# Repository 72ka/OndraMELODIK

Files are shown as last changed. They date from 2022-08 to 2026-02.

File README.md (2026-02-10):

# OndraMELODIK

 Music interface for the famous czechoslovak home computer [TESLA Ondra SPO186](http://www.ondraspo186.8u.cz/ "Tento web se zabývá československým počítačem Tesla Ondra SPO 186")

 SMD version with Joystick interface, but without printer connector by Solaris104 here: [Ondra JOY/MELODIK](http://www.ondraspo186.8u.cz/?p=641).
 
 You can read the OndraMELODIK story in [this article](http://www.ondraspo186.8u.cz/?p=588) (Czech language)

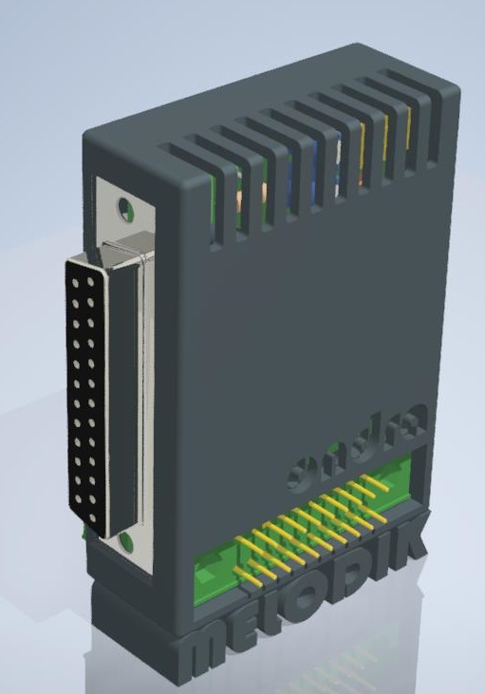
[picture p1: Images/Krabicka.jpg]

> OndraMELODIK music interface - introduced in 2022


> Czechoslovak home computer Tesla Ondra SPO186 - introduced in 1985

### Features

- Opensource hardware
- Based on [SN76489](https://en.wikipedia.org/wiki/Texas_Instruments_SN76489) chip
- Compatible with [OndraSD](https://sites.google.com/site/ondraspo186/4-rom-card-sd) interface, OndraMELODIK is through out interface
- It can play 3 channels square wave, 1 channel noise simultaneously
- Minimum CPU usage - two byte transfer, in some cases even one byte transfer, this is essential for such a slow computer
- External interface - no changes on the computer
- Designed with 80´ technology - all parts was available in 1985
- DB25 Centronics printer port (formerly known as LPT from PC) in one case
- 3D printed case STL files included

### Usage

1. Turn off your belowed Ondra
2. Plug OndraMELODIK to Ondra X1 connector
3. Optionally plug the OndraSD or whatever interface to the OndraMELODIK

#### As music interface

4. Switch the switch to the MELODIK position
5. Plug the 3.5mm audio jack of your favorite audio system
6. Turn on Ondra
7. If you hear some noise or tone, just push once the RESET button
8. Load the software [meltest.bin](https://github.com/72ka/OndraMELODIK/raw/main/Software/demo_test.bin) from this repository and test the device and listen the music

> Notice: If you perform just Ondra reset and some tone or noise is coming out, just push the RESET button once

#### As printer interface

4. Switch the switch to the PRINTER position
5. Be sure you dont have plugged in the audio jack or the audio system is turned off
6. Plug your printer using standard PC printer cable
7. Turn on Ondra
8. Print using Ondra's monitor, BASIC or TEDIT (if you forget to unplug the audio jack and strange noises are coming out, it is normal)

### Preview

How it sounds

https://www.youtube.com/watch?v=u5RyUs0VGdg

How it prints

https://www.youtube.com/watch?v=VYsxnQOKPeM

### Real photos

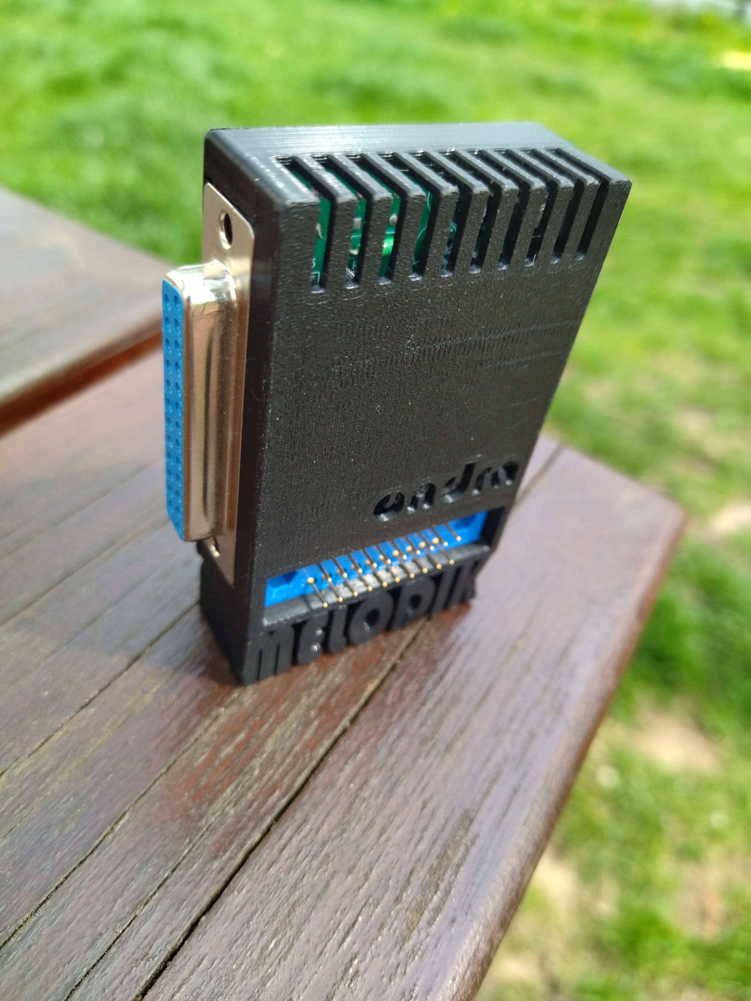
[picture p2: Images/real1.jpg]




### License

MIT license

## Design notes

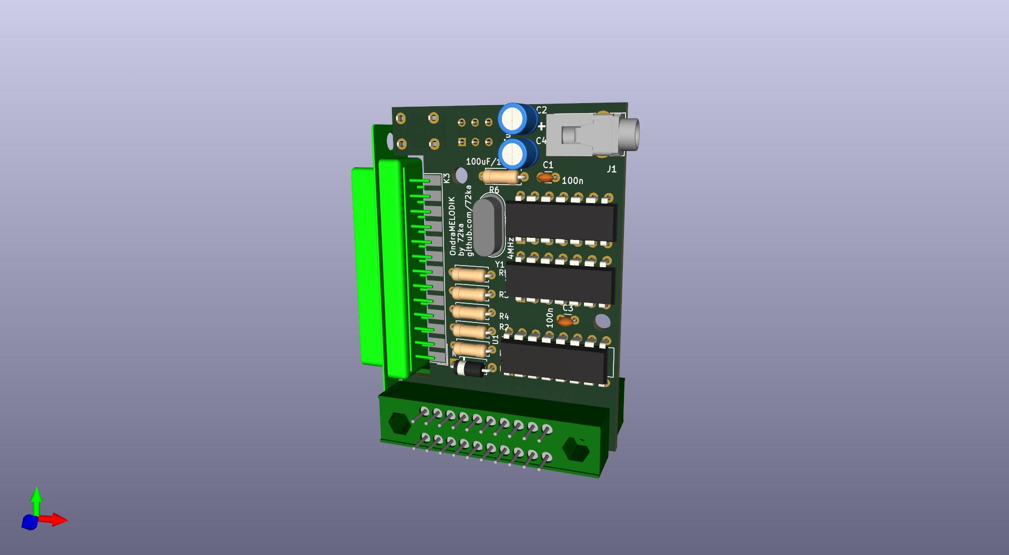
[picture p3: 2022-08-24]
Images/OndraMelodikTisk_zadek.jpg

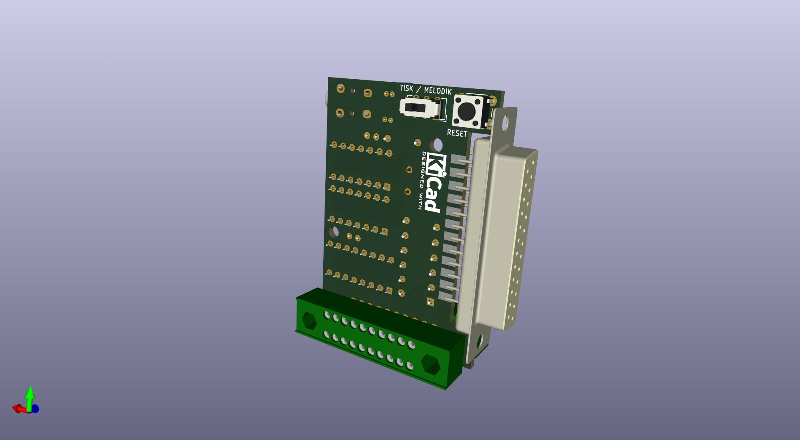
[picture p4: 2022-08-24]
Images/OndraMelodikTisk_predek.jpg

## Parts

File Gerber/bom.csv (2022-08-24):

Designator | Footprint | Quantity | Value | LCSC Part #
U3 | DIP-14_W7.62mm | 1 | 74LS74
R6 | R_Axial_DIN0207_L6.3mm_D2.5mm_P7.62mm_Horizontal | 1 | 2k
R2 | R_Axial_DIN0207_L6.3mm_D2.5mm_P7.62mm_Horizontal | 1 | 470R
R4 | R_Axial_DIN0207_L6.3mm_D2.5mm_P7.62mm_Horizontal | 1 | 10k
U1 | DIP-16_W7.62mm | 1 | SN76489
C4 | C_Radial_D6.3mm_H7.0mm_P2.50mm | 1 | 100uF/6,3V
R5 | R_Axial_DIN0207_L6.3mm_D2.5mm_P7.62mm_Horizontal | 1 | 10k
K2 | TX5112011 | 1 | ONDRA_X1
C1 | C_Disc_D3.0mm_W1.6mm_P2.50mm | 1 | 100n
K3 | DSUB-25_Female_EdgeMount_P2.77mm | 1 | Printer (optional)
U2 | DIP-14_W7.62mm | 1 | 74LS00
R1 | R_Axial_DIN0207_L6.3mm_D2.5mm_P7.62mm_Horizontal | 1 | 470R
D1 | D_A-405_P7.62mm_Horizontal | 1 | KA206
R3 | R_Axial_DIN0207_L6.3mm_D2.5mm_P7.62mm_Horizontal | 1 | 12k
C2 | C_Radial_D5.0mm_H7.0mm_P2.00mm | 1 | 4,7uF/50V
C3 | C_Disc_D3.0mm_W1.6mm_P2.50mm | 1 | 100n
J1 | Jack_3.5mm_Lumberg_1503_07_Horizontal | 1 | AudioJack
K1 | TX5112011 | 1 | ONDRA_X1
Y1 | Crystal_HC49-4H_Vertical | 1 | 4MHz
SW1 | SW_PUSH_6mm | 1 | RESET
SW2 | SW_CuK_JS202011CQN_DPDT_Straight | 1 | MELODIK / TISK

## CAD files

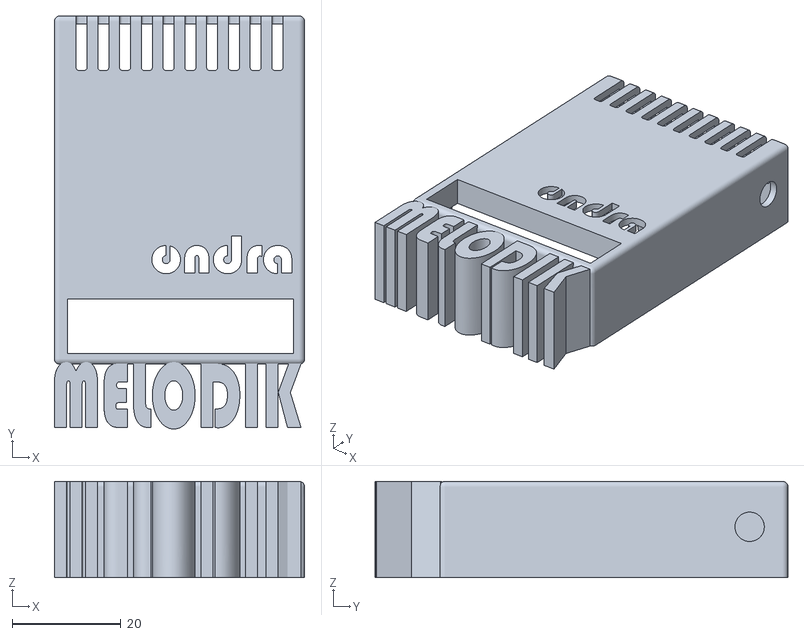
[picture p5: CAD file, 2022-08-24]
Case/Krabicka1.stl
46.0 x 75.9 x 17.7

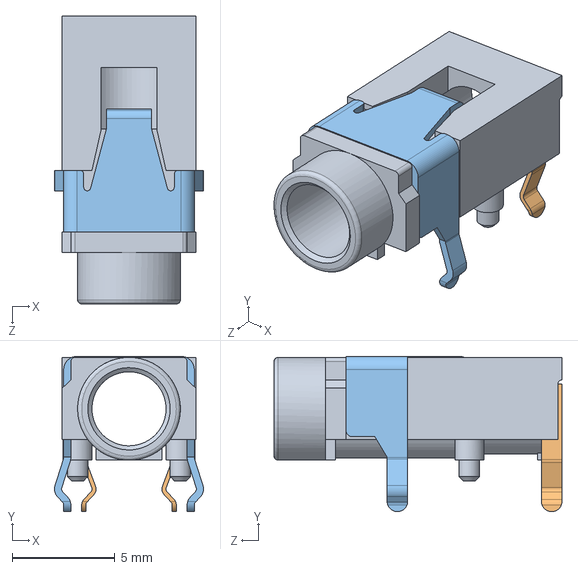
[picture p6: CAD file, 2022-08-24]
KiCAD/Lumberg_1503_07.stp
7.25 x 7.55 x 14.0 mm

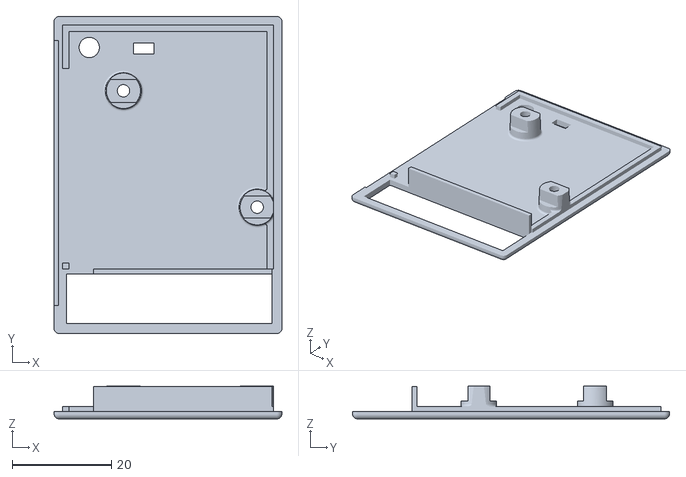
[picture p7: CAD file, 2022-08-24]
Case/Krabicka2.stl
46.0 x 64.0 x 6.60

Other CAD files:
Case/Deska.ipt
Case/Krabicka.iam
Case/Krabicka.ipt
Case/Vicko.ipt
Case/top.ipt

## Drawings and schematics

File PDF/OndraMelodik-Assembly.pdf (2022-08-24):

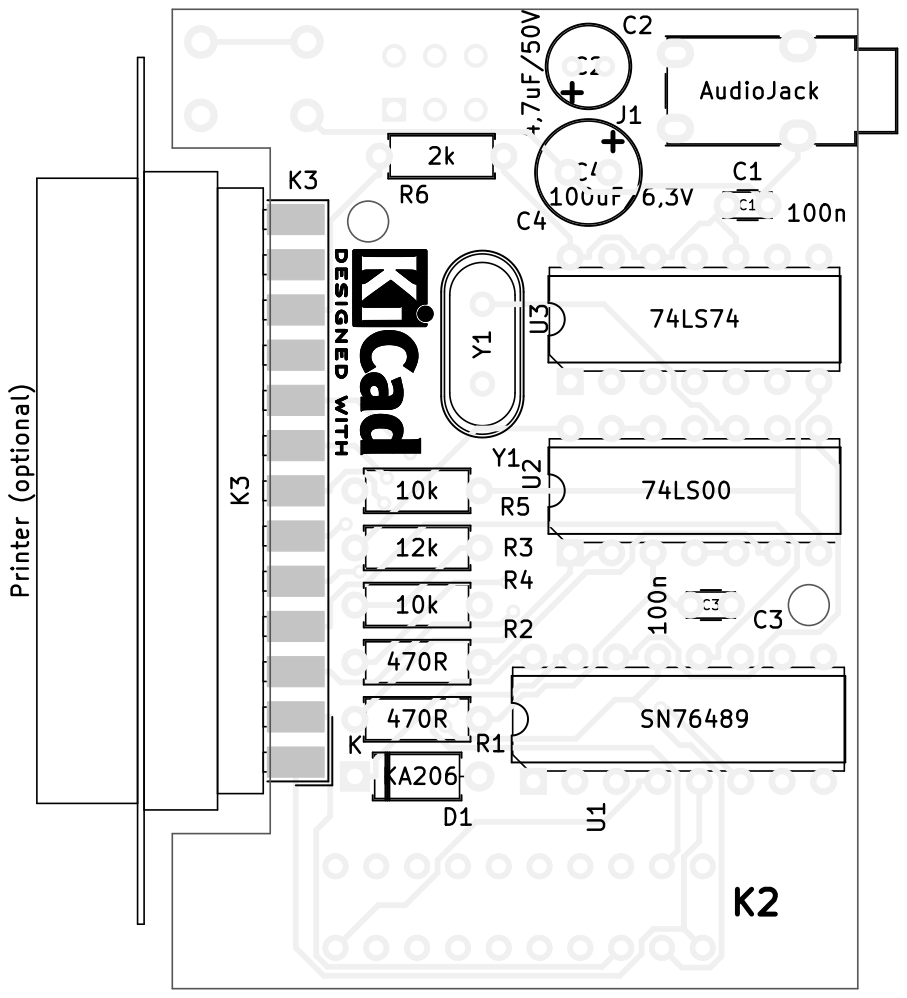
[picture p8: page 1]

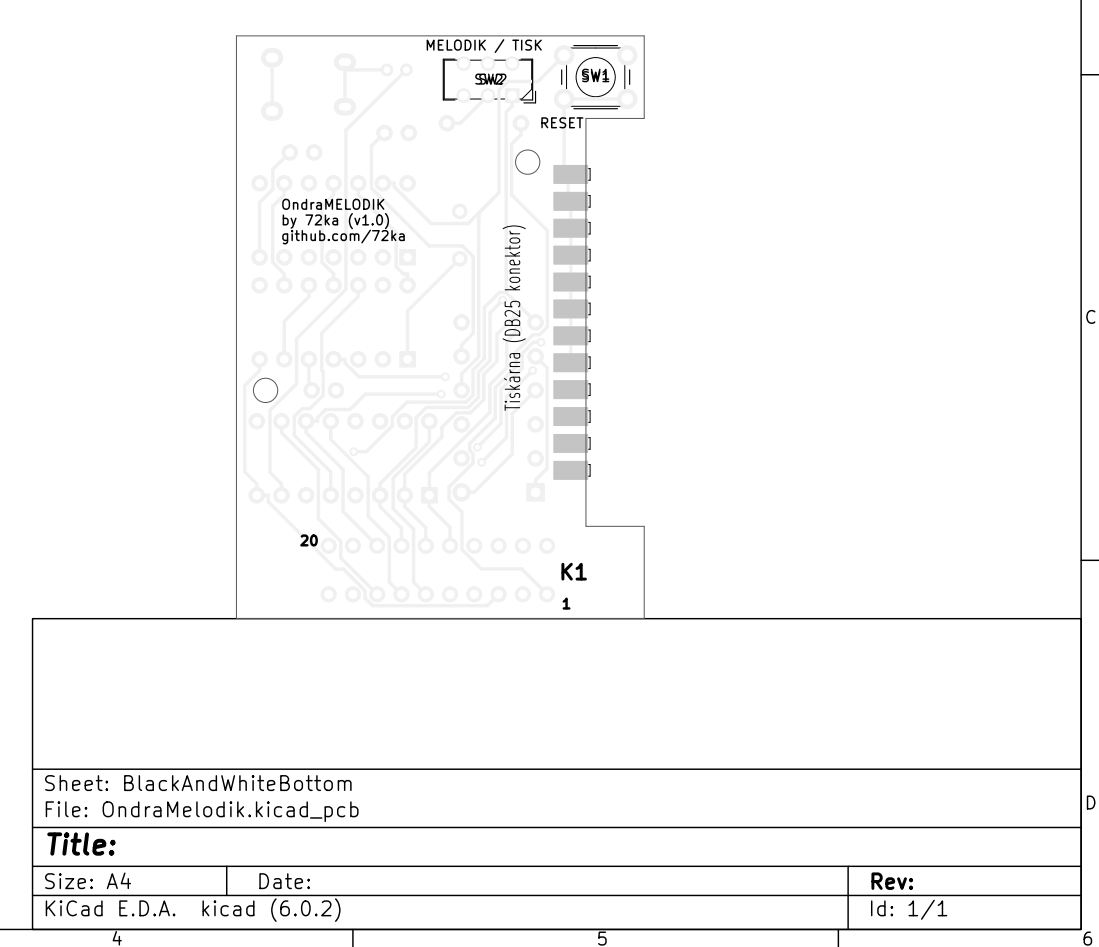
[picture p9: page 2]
D Date: KiCad E.D.A. kicad (6.0.2) Size: A4; Rev:; SW1 OndraMELODIK; by 72ka (v1.0) github.com/72ka; Tiskárna ⁽DB²⁵ konektor⁾ 20

SW1 RESET SW2 MELODIK / TISK

File: OndraMelodik.kicad_pcb Sheet: BlackAndWhiteBottom
Id: 1/1 Title:

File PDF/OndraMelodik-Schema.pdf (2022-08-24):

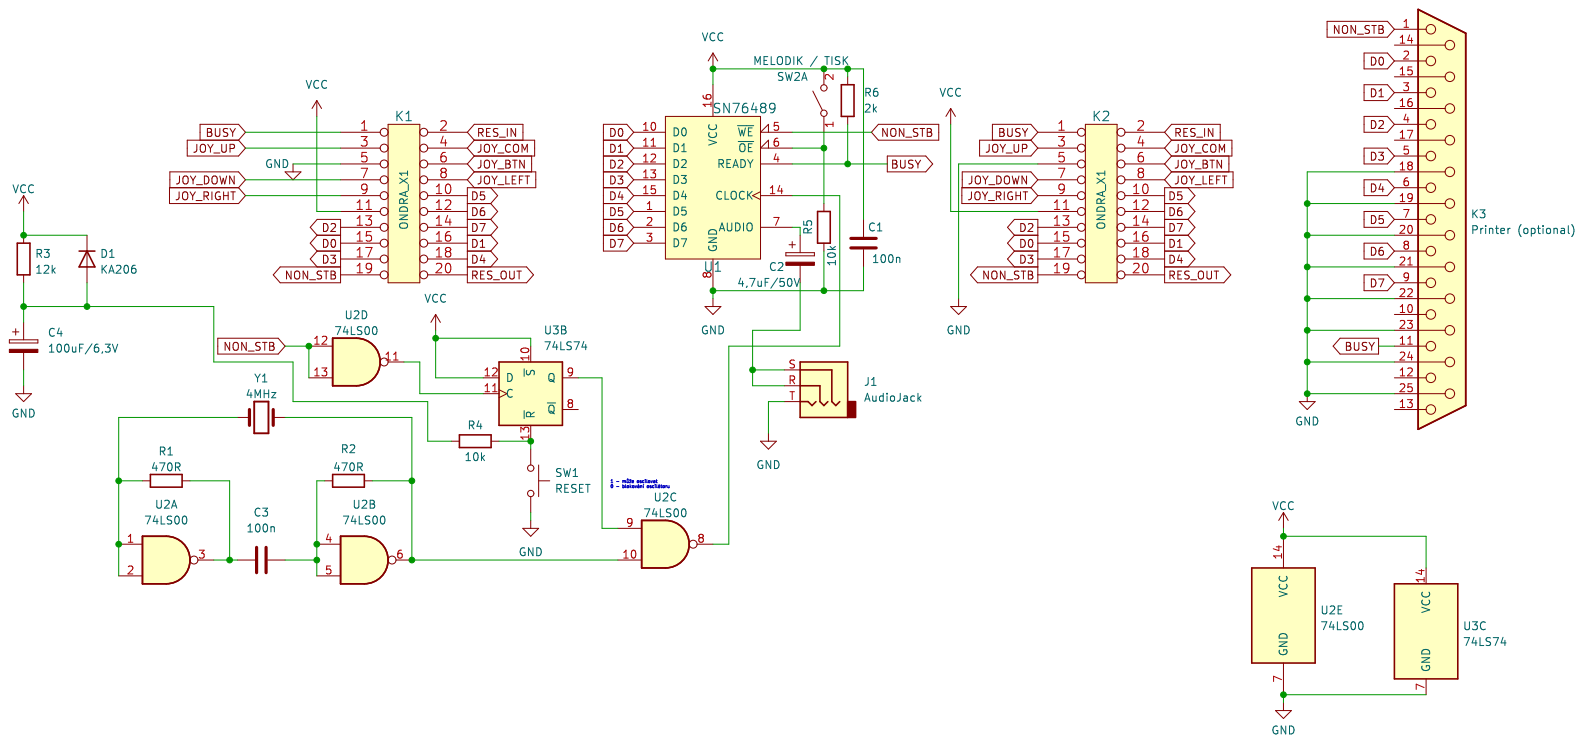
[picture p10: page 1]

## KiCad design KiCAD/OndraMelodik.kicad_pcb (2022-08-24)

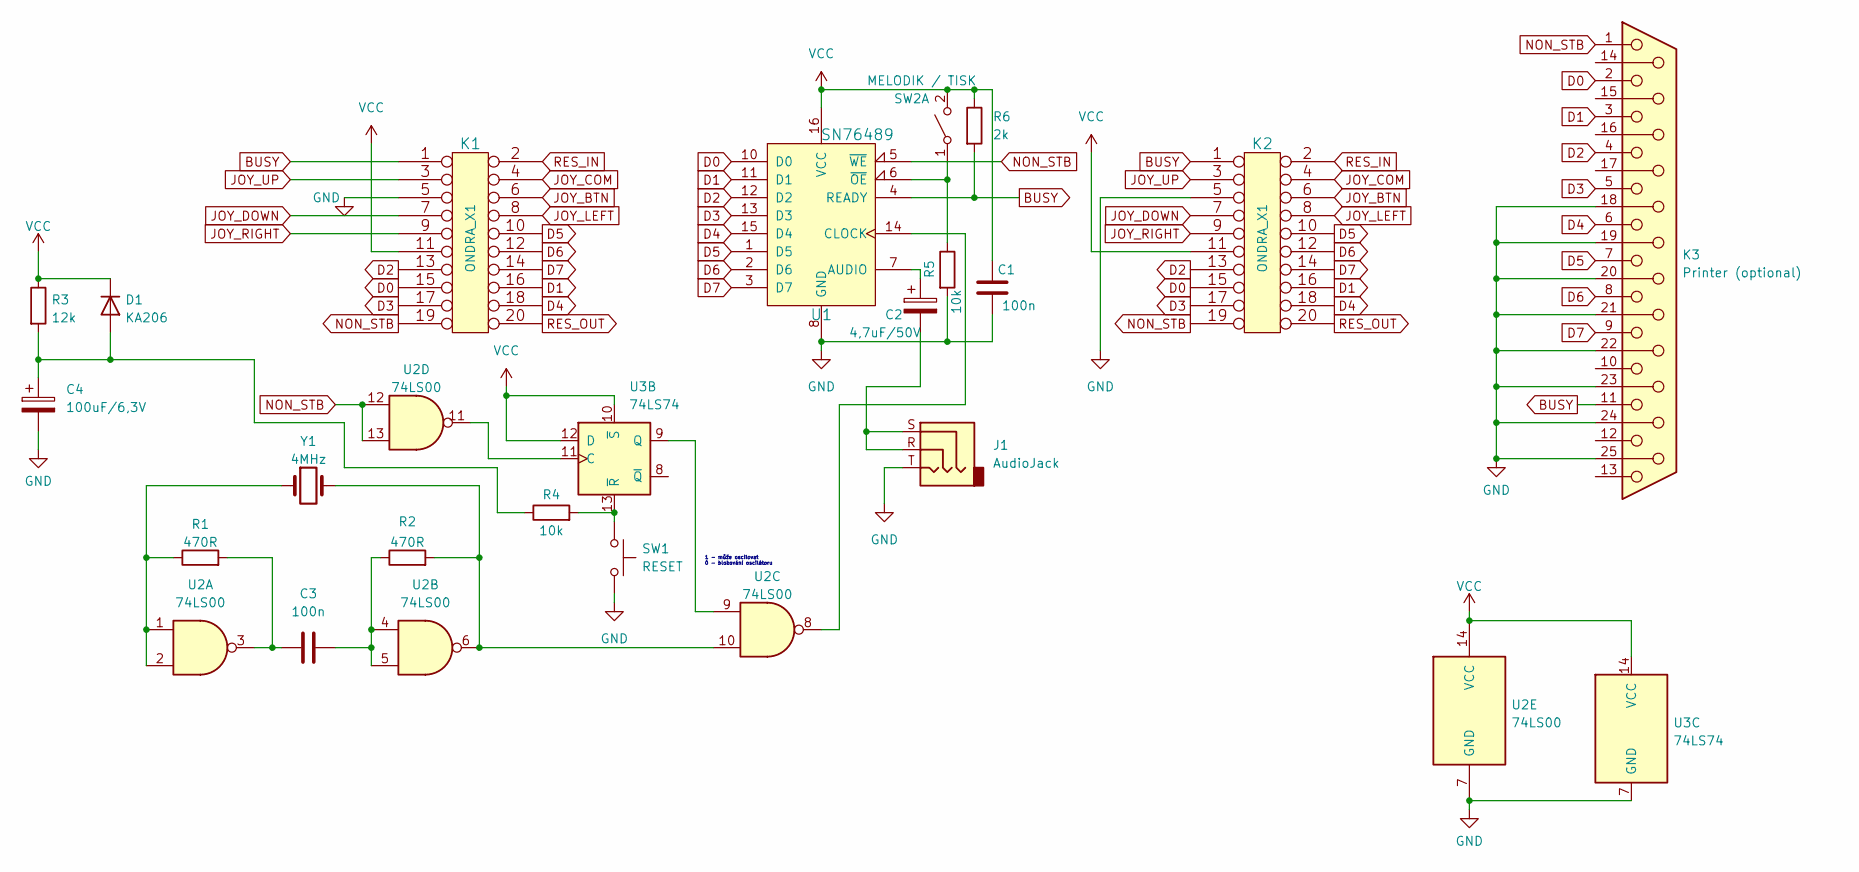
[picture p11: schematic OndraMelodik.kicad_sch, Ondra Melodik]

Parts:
C1, C3: 100n; C_Disc_D3.0mm_W1.6mm_P2.50mm
C2: 4,7uF/50V; C_Radial_D5.0mm_H7.0mm_P2.00mm
C4: 100uF/6,3V; C_Radial_D6.3mm_H7.0mm_P2.50mm
D1: KA206; D_A-405_P7.62mm_Horizontal
J1: AudioJack; Jack_3.5mm_Lumberg_1503_07_Horizontal
K1, K2: ONDRA_X1; TX5112011
K3: Printer (optional); DSUB-25_Female_EdgeMount_P2.77mm
R1, R2: 470R; R_Axial_DIN0207_L6.3mm_D2.5mm_P7.62mm_Horizontal
R3: 12k; R_Axial_DIN0207_L6.3mm_D2.5mm_P7.62mm_Horizontal
R4, R5: 10k; R_Axial_DIN0207_L6.3mm_D2.5mm_P7.62mm_Horizontal
R6: 2k; R_Axial_DIN0207_L6.3mm_D2.5mm_P7.62mm_Horizontal
SW1: RESET; SW_PUSH_6mm
SW2: MELODIK / TISK; SW_CuK_JS202011CQN_DPDT_Straight
U1: SN76489; DIP-16_W7.62mm
U2: 74LS00; DIP-14_W7.62mm
U3: 74LS74; DIP-14_W7.62mm
Y1: 4MHz; Crystal_HC49-4H_Vertical

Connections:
BUSY: K1.1, K2.1, K3.11, R6.2, U1.4 (READY)
D0: K1.15, K2.15, K3.2, U1.10 (D0)
D1: K1.16, K2.16, K3.3, U1.11 (D1)
D2: K1.13, K2.13, K3.4, U1.12 (D2)
D3: K1.17, K2.17, K3.5, U1.13 (D3)
D4: K1.18, K2.18, K3.6, U1.15 (D4)
D5: K1.10, K2.10, K3.7, U1.1 (D5)
D6: K1.12, K2.12, K3.8, U1.2 (D6)
D7: K1.14, K2.14, K3.9, U1.3 (D7)
GND: C1.2, C4.2, J1.T, K1.5, K2.5, K3.18, K3.19, K3.20, K3.21, K3.22, K3.23, K3.24, K3.25, R5.2, SW1.2, U1.8 (GND), U2.7 (GND), U3.7 (GND)
JOY_BTN: K1.6, K2.6
JOY_COM: K1.4, K2.4
JOY_DOWN: K1.7, K2.7
JOY_LEFT: K1.8, K2.8
JOY_RIGHT: K1.9, K2.9
JOY_UP: K1.3, K2.3
NON_STB: K1.19, K2.19, K3.1, U1.5 (~WE), U2.12, U2.13
unnamed: C2.1, U1.7 (AUDIO)
unnamed: C2.2, J1.R, J1.S
unnamed: C3.1, R1.2, U2.3
unnamed: C3.2, R2.1, U2.4, U2.5
unnamed: C4.1, D1.2 (A), R3.2, R4.1
unnamed: R1.1, U2.1, U2.2, Y1.1
unnamed: R2.2, U2.6, U2.10, Y1.2
unnamed: R4.2, SW1.1, U3.13 (~R)
unnamed: R5.1, SW2.1 (A), U1.6 (~OE)
unnamed: U1.14 (CLOCK), U2.8
unnamed: U2.9, U3.9 (Q)
unnamed: U2.11, U3.11 (C)
RES_IN: K1.2, K2.2
RES_OUT: K1.20, K2.20
VCC: C1.1, D1.1 (K), K1.11, K2.11, R3.1, R6.1, SW2.2 (B), U1.16 (VCC), U2.14 (VCC), U3.10 (~S), U3.12 (D), U3.14 (VCC)

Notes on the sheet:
1 - může oscilovat 0 - blokování oscilátoru

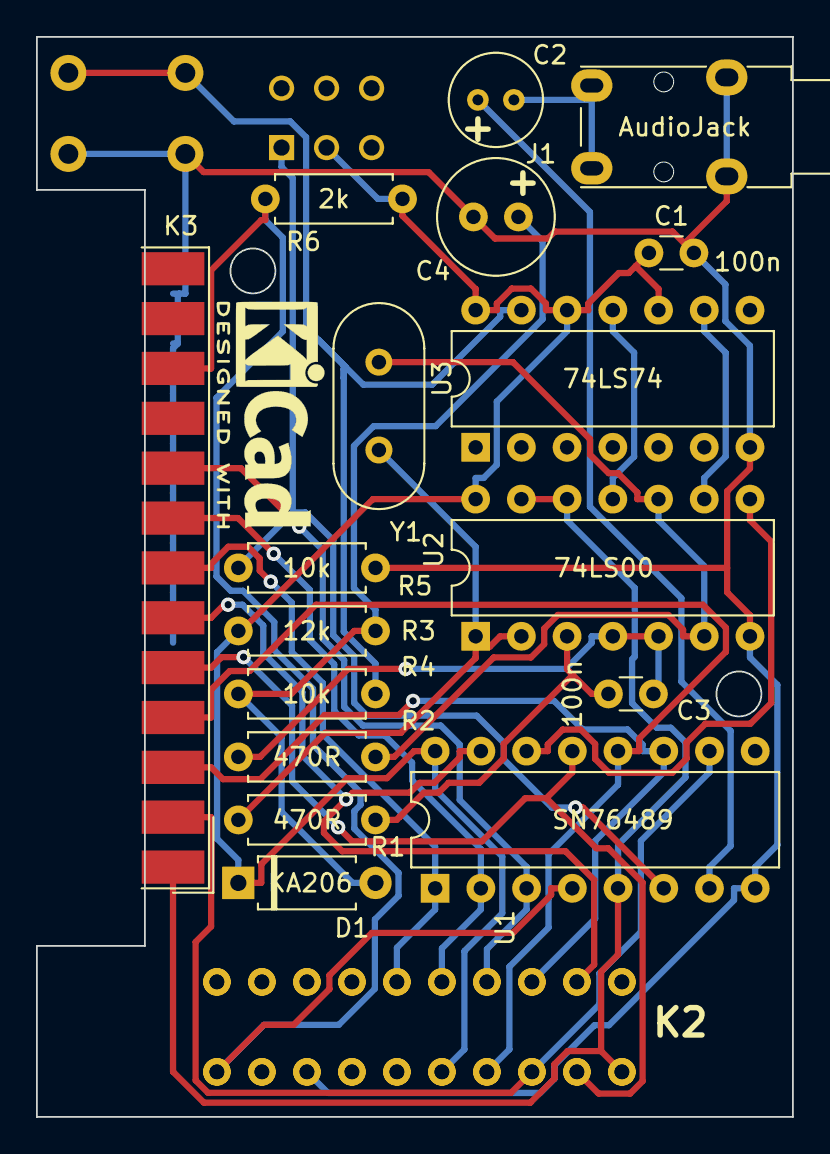
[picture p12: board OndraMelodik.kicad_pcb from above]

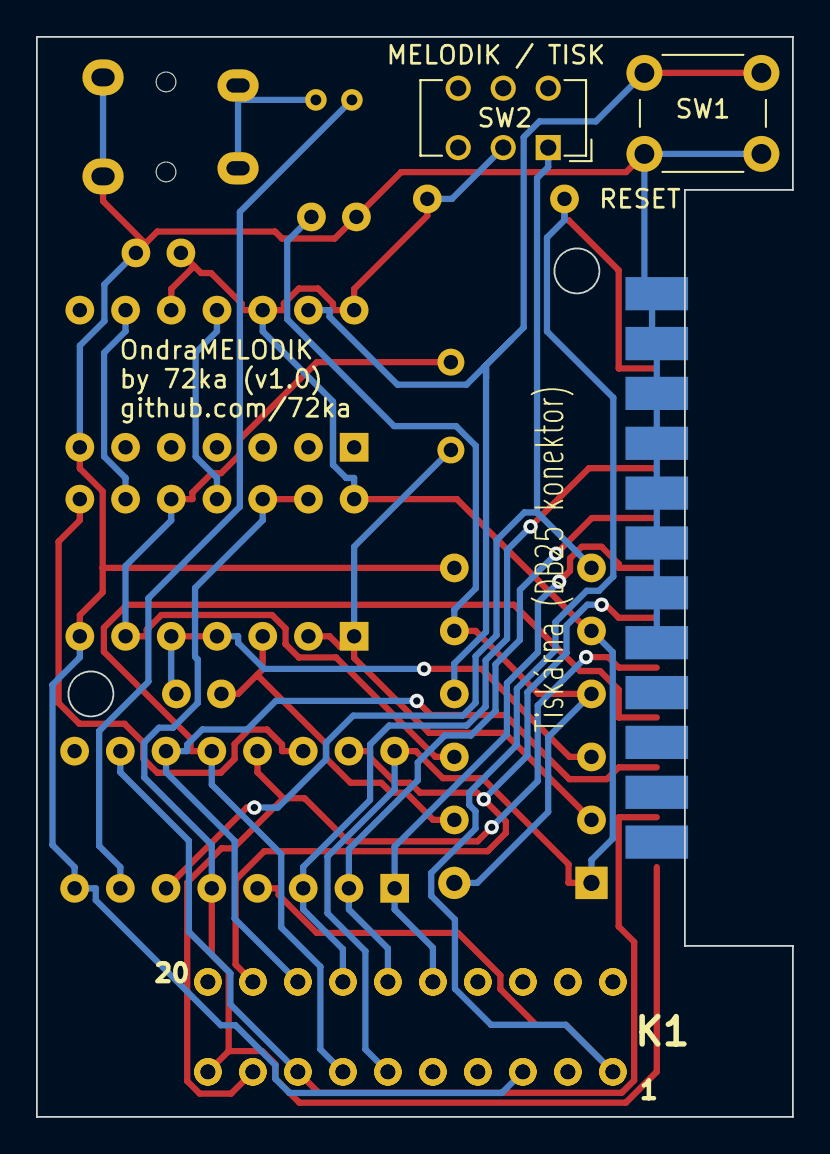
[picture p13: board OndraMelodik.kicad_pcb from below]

Board: 2 copper layers, 42.0 x 60.0 mm, 21 parts (2 on the bottom side), 32 nets.
